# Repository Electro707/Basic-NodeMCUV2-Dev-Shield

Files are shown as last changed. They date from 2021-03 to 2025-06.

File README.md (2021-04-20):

# E707 Basic NodeMCU-V2 Shield 

PCB 3D Preview

This shield/daughterboard is for the NodeMCU V2 (also known as NodeMCU DevKit V1.0, kind of confusing) to allow a begineer to have some components to play around with. In this case, that includes a 7-segment display, an RGB LED (which is hooked up with the 7-segment display), and 3 pushbuttons.

### Arduino Library

The Arduino library for this shield can be found at: [https://github.com/Electro707/Basic-NodeMCUV2-Dev-Shield-Library](https://github.com/Electro707/Basic-NodeMCUV2-Dev-Shield-Library). It provides pin definitions and more importantly some examples to get started with.

The reason it's in a different repo is to allow for an easy download of the library as a ZIP file (using GitHub's "Download ZIP" option) to be easily imported into the Arduino IDE. 

### PCB

The PCB files can be found in the `KiCAD Files` folder. 

There are different folders for different PCB layouts. More details can be found in [KiCAD_Files/README.md](KiCAD_Files/README.md)

#### PCB Panel

There is a panel (not tested tough) of the PCB for mass-production:

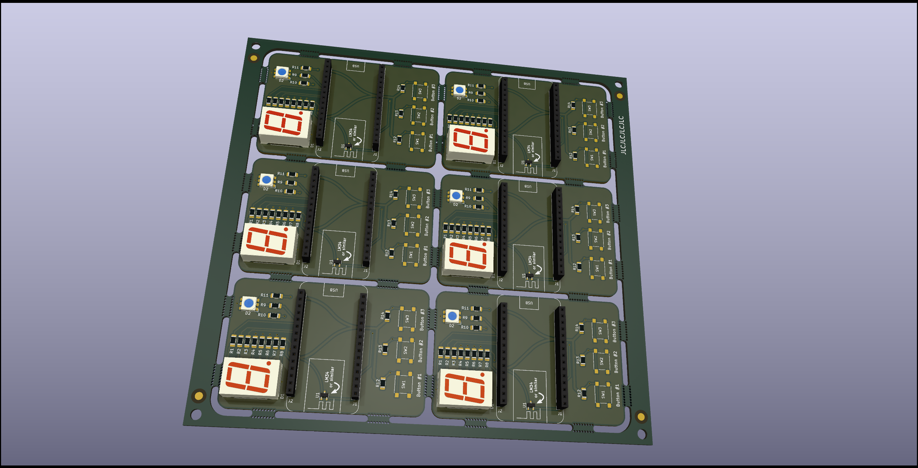
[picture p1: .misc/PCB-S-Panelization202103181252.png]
Panel Picture


##### NOTE: If you have KiCAD 5.1.9 or lower, the KiCAD files will not open as it was designed with KiCAD 5.99 (the alpha/beta version of KiCAD V6).

### Docs 
Coming Soon!

### Credits:
- Creator and Maintainer:
    - Electro707 (Jamal Bouajjaj)
- KiCAD NODEMCU V2 Symbol:
    - jdunmire -> [https://github.com/jdunmire/kicad-ESP8266](https://github.com/jdunmire/kicad-ESP8266)
- Some Icons:
    - Arduino's IDE Repo -> [https://github.com/arduino/Arduino/blob/master/build/shared/lib/theme/buttons.svg](https://github.com/arduino/Arduino/blob/master/build/shared/lib/theme/buttons.svg)

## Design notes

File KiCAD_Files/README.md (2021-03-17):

# KiCAD Files Versions

There are different folders in this directory, and they are different versions of this shield. The schematic is all the same, the difference lying in the PCB layout/footprints.

- Standard-S: The regular SMD version of the board, optimized for mass production.
- Standard-T: The regular THT version of the board, optimized to be used as a soldering kit.
- UNewHaven-S: The University of New Haven version, used for the school's "Welcome Kit" something. Optimized for mass production.

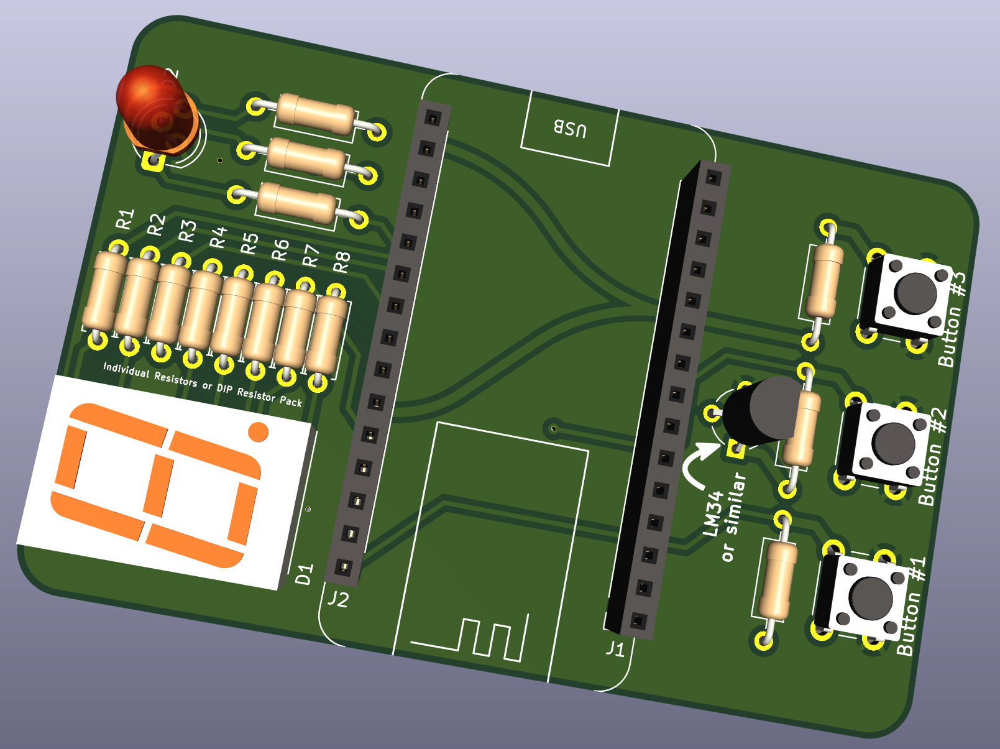
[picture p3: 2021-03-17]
.misc/Screenshot_20210317_004601.png

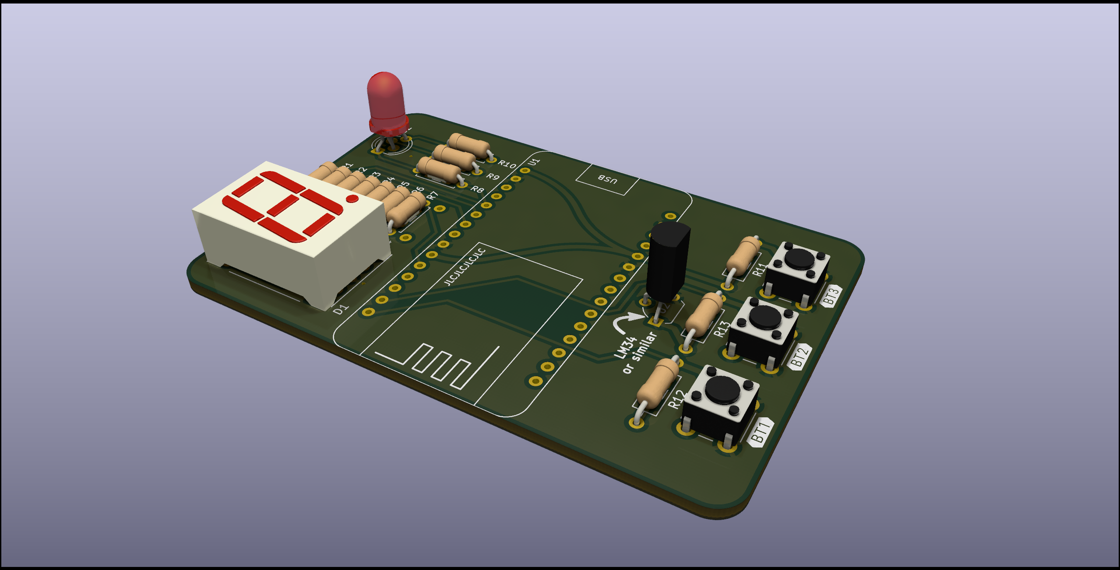
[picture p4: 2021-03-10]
.misc/pcb-prev-1.png

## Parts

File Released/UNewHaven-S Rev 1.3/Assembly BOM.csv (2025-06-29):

Comment | Designator | Footprint | LCSC
SM420561N | D1 | Display_7Segment:7SegmentLED_LTS6760_LTS6780 | C141367
LED_RGB | D2 | LED_SMD:LED_RGB_5050-6 | C784540
Conn_01x15_Female | J1,J2 | Connector_PinSocket_2.54mm:PinSocket_1x15_P2.54mm_Vertical | C124408
330 | R1,R2,R3,R4,R5,R6,R7,R8,R9,R10,R11 | Resistor_SMD:R_1206_3216Metric_Pad1.30x1.75mm_HandSolder | C17930
1k | R12,R13,R14,R15 | Resistor_SMD:R_1206_3216Metric_Pad1.30x1.75mm_HandSolder | C4410
SW_Push_DPDT | SW-T1,SW-T2,SW-T3 | Button_Switch_THT:SW_CuK_JS202011CQN_DPDT_Straight | C221666
SW_Push | SW1,SW2,SW3 | Button_Switch_SMD:SW_Push_1P1T_NO_6x6mm_H9.5mm | C136669
MCP9700AT-ETT | U1 | Package_TO_SOT_SMD:SOT-23 | C127949

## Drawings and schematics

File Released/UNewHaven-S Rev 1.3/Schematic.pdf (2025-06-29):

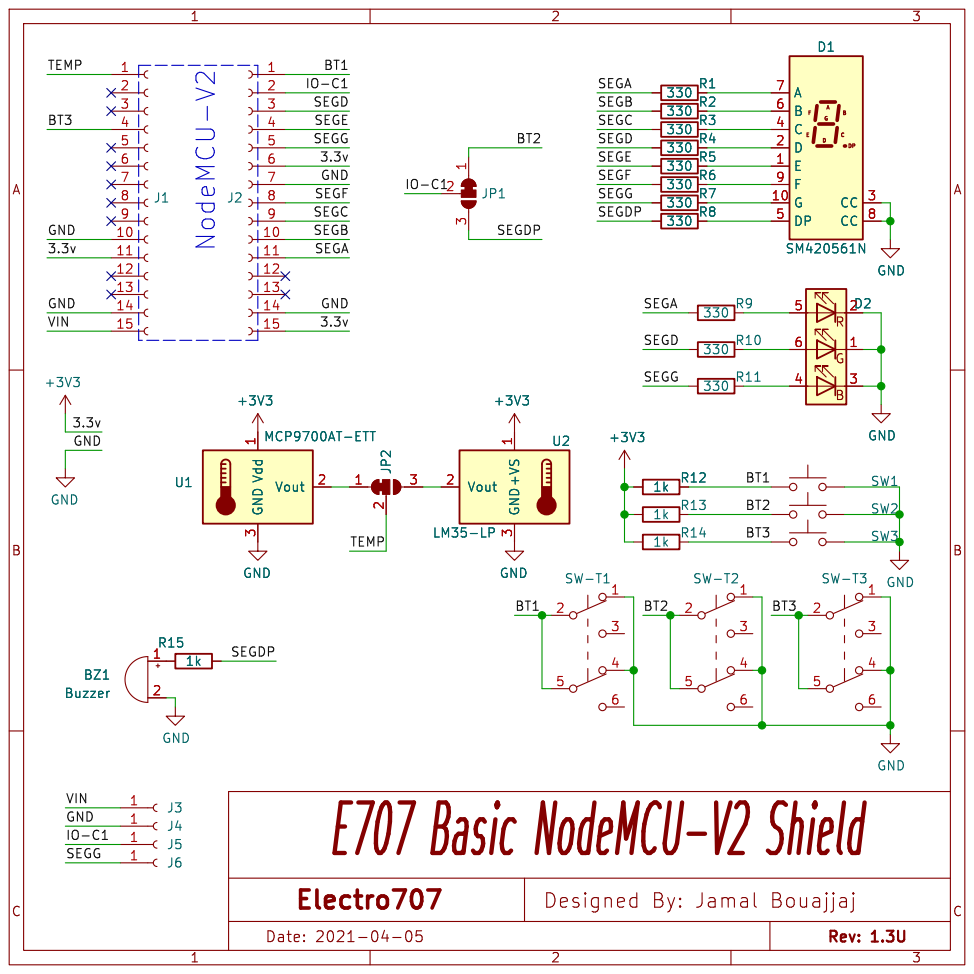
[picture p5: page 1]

E707 Basic NodeMCU-V2 Shield

Electro707

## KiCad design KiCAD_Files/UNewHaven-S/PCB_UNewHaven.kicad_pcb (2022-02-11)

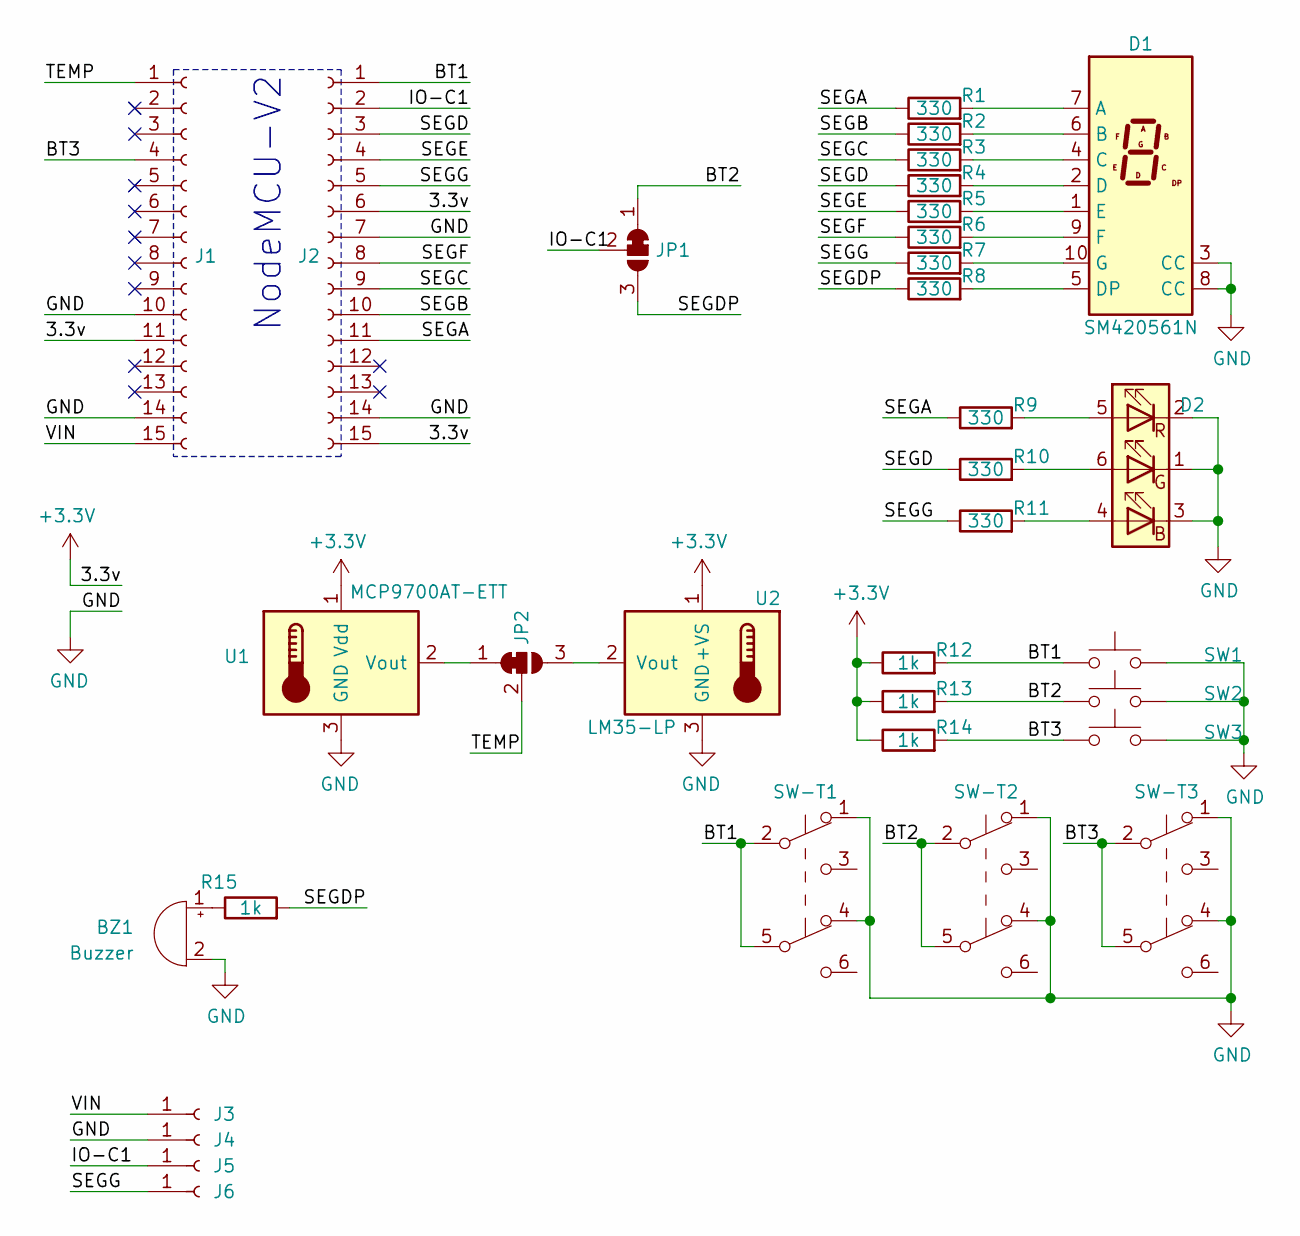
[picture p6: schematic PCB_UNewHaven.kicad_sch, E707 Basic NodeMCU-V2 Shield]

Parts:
BZ1: Buzzer; Buzzer_12x9.5RM7.6
D1: SM420561N; 7SegmentLED_LTS6760_LTS6780
D2: LED_RGB; LED_RGB_5050-6; LCSC C784540
J1, J2: Conn_01x15_Female; PinSocket_1x15_P2.54mm_Vertical
J3, J4, J5, J6: Conn_01x01_Female; SingleExternalWire
JP1, JP2: SolderJumper_3_Bridged12; SolderJumper-3_P1.3mm_Bridged12_Pad1.0x1.5mm
R1, R2, R3, R4, R5, R6, R7, R8, R9, R10, R11: 330; R_1206_3216Metric_Pad1.30x1.75mm_HandSolder
R12, R13, R14, R15: 1k; R_1206_3216Metric_Pad1.30x1.75mm_HandSolder
SW1, SW2, SW3: SW_Push; SW_Push_1P1T_NO_6x6mm_H9.5mm
SW-T1, SW-T2, SW-T3: SW_Push_DPDT; SW_CuK_JS202011CQN_DPDT_Straight
U1: MCP9700AT-ETT; SOT-23
U2: LM35-LP; TO-92L_Wide

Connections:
+3V3: J1.11, J2.6, J2.15, R12.1, R13.1, R14.1, U1.1 (Vdd), U2.1 (+VS)
/BT1: J2.1, R12.2, SW1.1, SW-T1.2 (B), SW-T1.5 (B)
/BT2: JP1.1 (A), R13.2, SW2.1, SW-T2.2 (B), SW-T2.5 (B)
/BT3: J1.4, R14.2, SW3.1, SW-T3.2 (B), SW-T3.5 (B)
/IO-C1: J2.2, J5.1, JP1.2 (C)
/SEGA: J2.11, R1.1, R9.1
/SEGB: J2.10, R2.1
/SEGC: J2.9, R3.1
/SEGD: J2.3, R4.1, R10.1
/SEGDP: JP1.3 (B), R8.1, R15.2
/SEGE: J2.4, R5.1
/SEGF: J2.8, R6.1
/SEGG: J2.5, J6.1, R7.1, R11.1
/TEMP: J1.1, JP2.2 (C)
/VIN: J1.15, J3.1
GND: BZ1.2 (+), D1.3 (CC), D1.8 (CC), D2.1 (GK), D2.2 (RK), D2.3 (BK), J1.10, J1.14, J2.7, J2.14, J4.1, SW1.2, SW2.2, SW3.2, SW-T1.1 (A), SW-T1.4 (A), SW-T2.1 (A), SW-T2.4 (A), SW-T3.1 (A), SW-T3.4 (A), U1.3 (GND), U2.3 (GND)
unnamed: BZ1.1 (-), R15.1
unnamed: D1.1 (E), R5.2
unnamed: D1.2 (D), R4.2
unnamed: D1.4 (C), R3.2
unnamed: D1.5 (DP), R8.2
unnamed: D1.6 (B), R2.2
unnamed: D1.7 (A), R1.2
unnamed: D1.9 (F), R6.2
unnamed: D1.10 (G), R7.2
unnamed: D2.4 (BA), R11.2
unnamed: D2.5 (RA), R9.2
unnamed: D2.6 (GA), R10.2
unnamed: JP2.1 (A), U1.2 (Vout)
unnamed: JP2.3 (B), U2.2 (Vout)

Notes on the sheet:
NodeMCU-V2

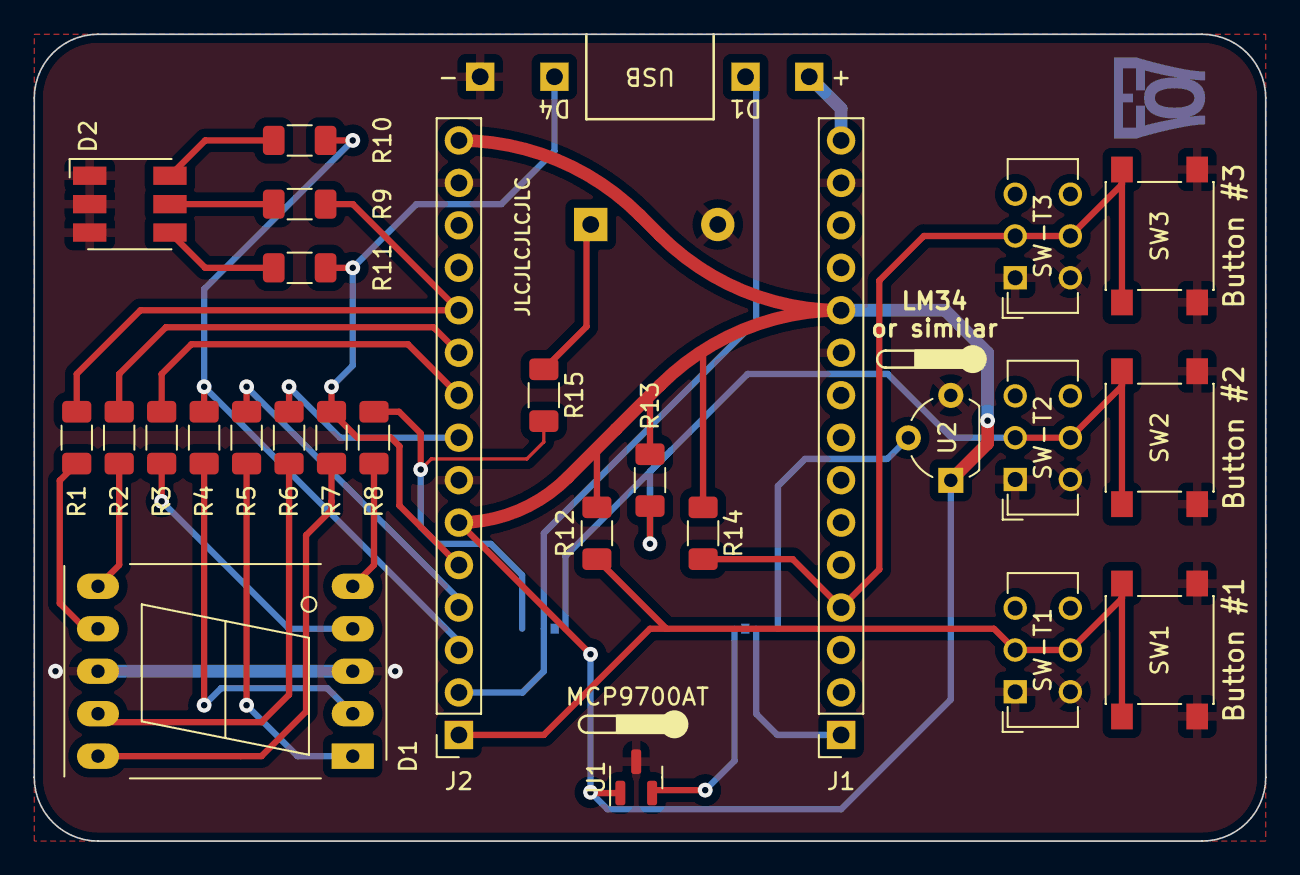
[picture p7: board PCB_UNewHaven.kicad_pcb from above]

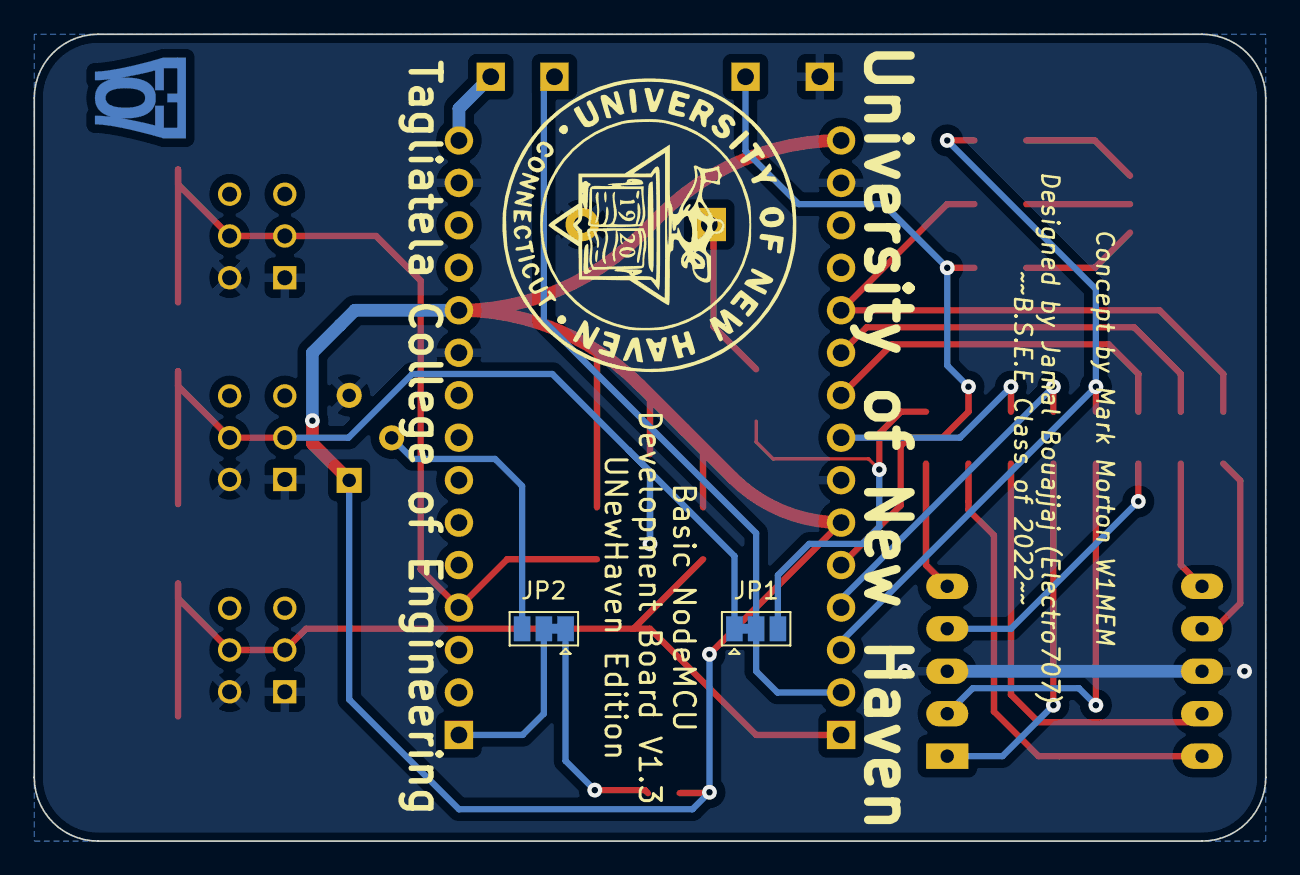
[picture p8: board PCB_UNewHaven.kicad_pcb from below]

Board: 2 copper layers, 73.7 x 48.3 mm, 36 parts (4 on the bottom side), 30 nets.

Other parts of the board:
Ref**: Val**; NPN_6x6mm
Ref**#2: Val**; NPN_6x6mm

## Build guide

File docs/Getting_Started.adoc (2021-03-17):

= E707 Basic NodeMCU-V2 Shield V1.1 Getting Started Guide
Electro707
V1.1, 2021-03-17
:toc:
:icons: font
// :doctype: book
:imagesdir: .images
<<<
== Intro
The purpose of this document is to be used as a "Getting Started" guide for the E707 Basic NodeMCU-V2 Shield. This document has been written for a beginner (somebody who has little to no experience with Arduino's or electronics) to get them up and running with the shield and upload a basic example to it.

NOTE: About the name of this board, the reason I have added `V2` to the `NodeMCU-V2` part of the name is to distuguishe that this shield is only compatible with that is widely refered as NodeMCU V2, instead of other varients/versions of the NodeMCU. The shield's version is what comes after the `Shield` part of the name. Sorry for any confusion.

== Prerequesites
=== Components
You should have the following 2 parts:

[cols="1,1"]
|===
|A NodeMCU V2 Development Board
|E707 Basic NodeMCU-V2 Shield

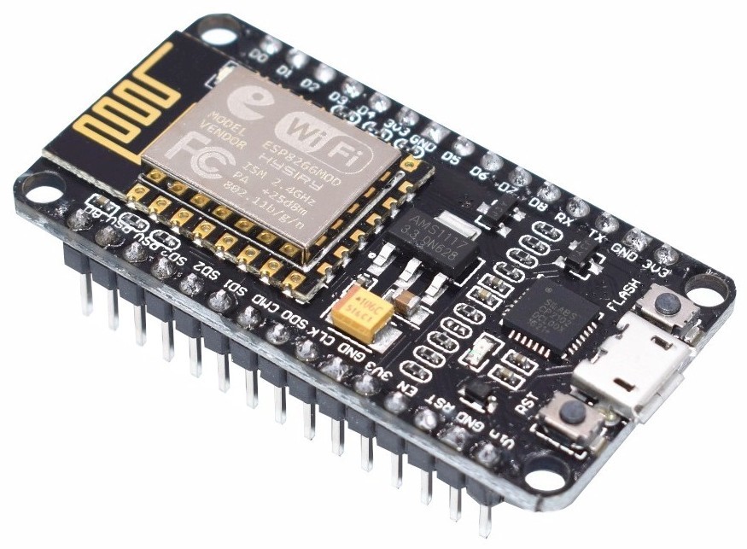
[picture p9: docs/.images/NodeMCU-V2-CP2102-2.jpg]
NodeMCU V2 Board Image
a|
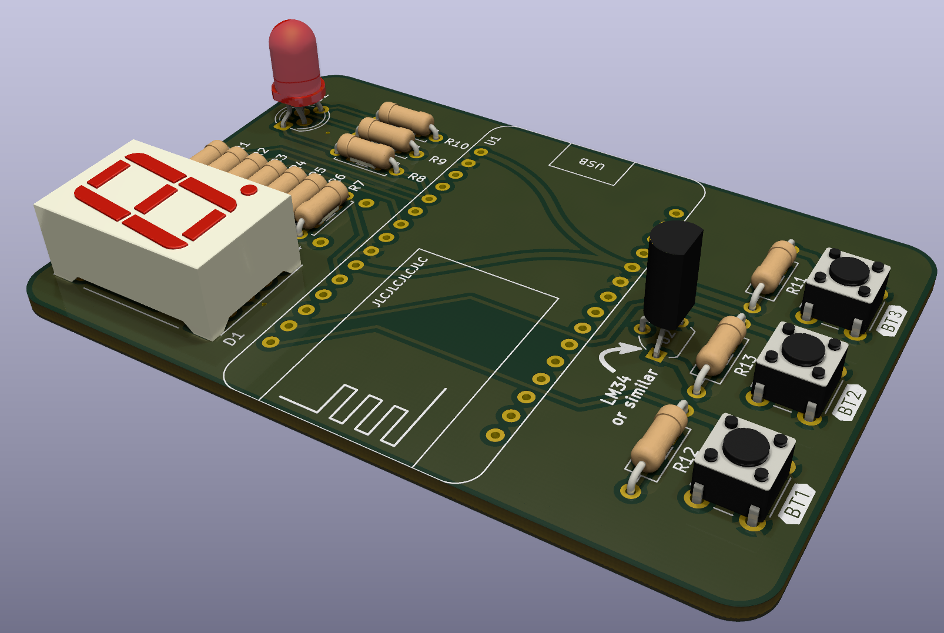
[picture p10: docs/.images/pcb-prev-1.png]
E707 Shield
a|
|===

If the NodeMCU isn't already plugged into the shield (plug it into the 2 pin headers on the board). 

NOTE: This assumes that the shield is already soldered. If it isn't and you have a plain PCB and components, checkout the Soldering Guide.

=== Software
==== Arduino IDE
We will be using the Arduino IDE (Integrated Development Environment) to create programs and upload them to the NodeMCU. While it is the most common way of doing so, there are other tools and IDEs out there like MicroPython for examples. 

If you don't have the Arduino IDE installed on you machine, you should do that now. The program's download page can be found at https://www.arduino.cc/en/software. They have a https://www.arduino.cc/en/Guide[Getting Started Guide] if you're having trouble installing the program.

==== ESP8266 Board Package
When you first install the Arduino IDE, it doesn't come with the ability to upload to ESP8266 based modules (like the NodeMCU), so we must add that. Open up the IDE and go into ``File->Preferences``. In the __Additional Board Managers URLs__ section, enter the following URL:
 
 https://arduino.esp8266.com/stable/package_esp8266com_index.json

This allows us to use the build-in Board Manager to install ESP8266 board. After that, exit out of the preferences menu (by clicking the __OK__ button) and go into ``Tools->Board->Board Manager``. Once the Board Manager menu pops us, type in `esp8266` in the filter entry and press Enter. You should see an `esp8266 by ESP8266 Community` board popup. 

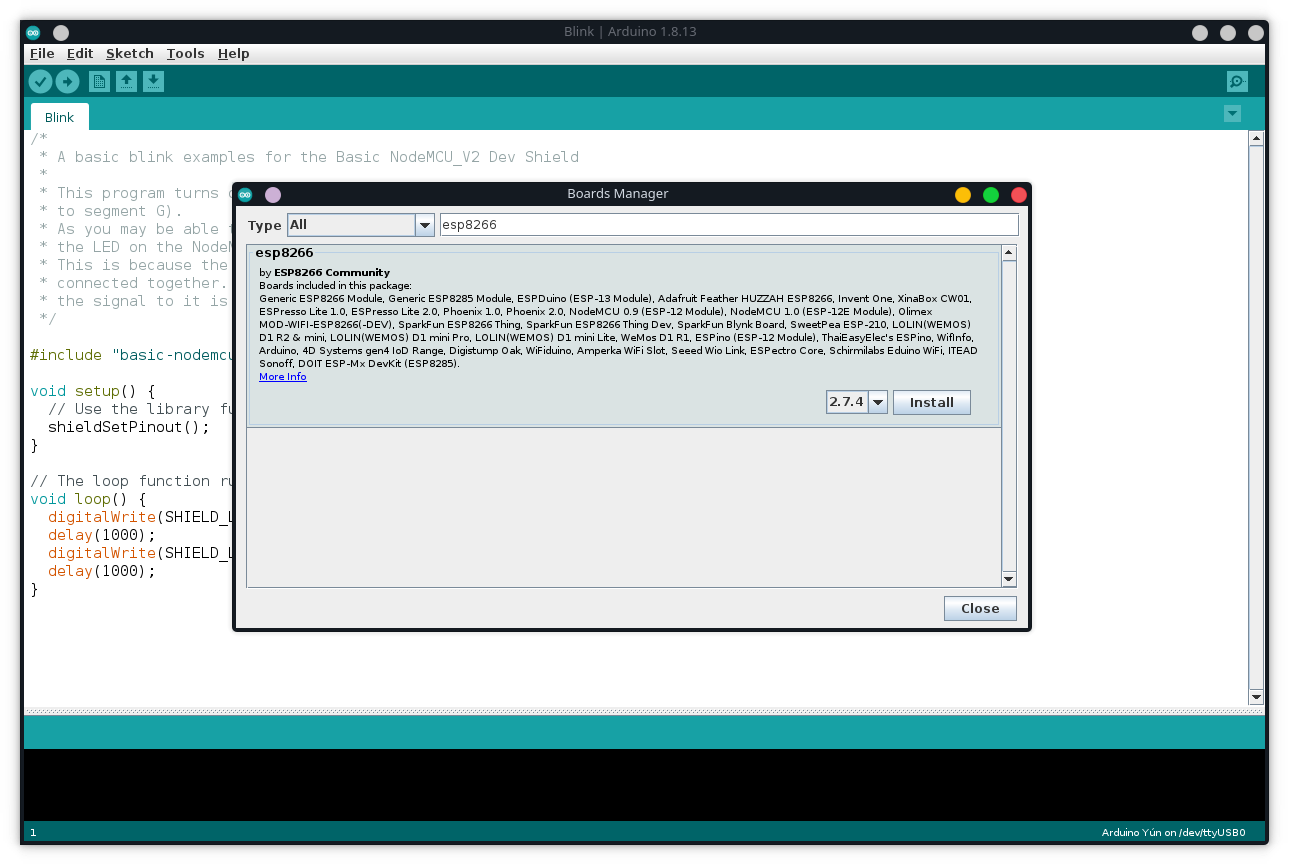
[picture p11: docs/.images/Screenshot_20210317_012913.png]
Board Manager image with esp8266


Click on the Install button for that board. The download and installation process might take a hot minute, so grab a quick cup of coffee in the meanwhile (or tea which is my personal favorite). After the installation process is complete, close out of the Board Manager (with the Close button). You are now able to compile and upload programs to ESP8266 based modules including the NodeMCU which we are using.

== E707 Basic NodeMCU-V2 Shield Library
While you can go right ahead and start using the shield by reading the schematic and seeing which periferals connect to where, a library was made for this shield to make that process simpler. It includes pin definitions, some helper functions (for the temperature sensor for example), and examples. 

To download the library, head over to it's repository on GitHub:

 https://github.com/Electro707/Basic-NodeMCUV2-Dev-Shield-Library

Then click on the ``Code->Download Zip`` button on the Github page to get a .zip file of the library. In the Arduino IDE, go to ``Sketch->Include Library->Add .ZIP Library``. Browse to the download location of the library and select it. 

== Lets Light This Place Up
Now let's make some LEDs blink on the Dev. Shield. Go to and select ``Files->Examples->E707 Basic NodeMCU-V2 Shield->Blink``. A new sketch should pop up with some pre-written code. 

New let's select the right board to compile and upload to. In the Tools menu, for the Board select `NodeMCU 1.0 (ESP-12E Module)` board. The rest of the settings should be fines, and it should look like the following:

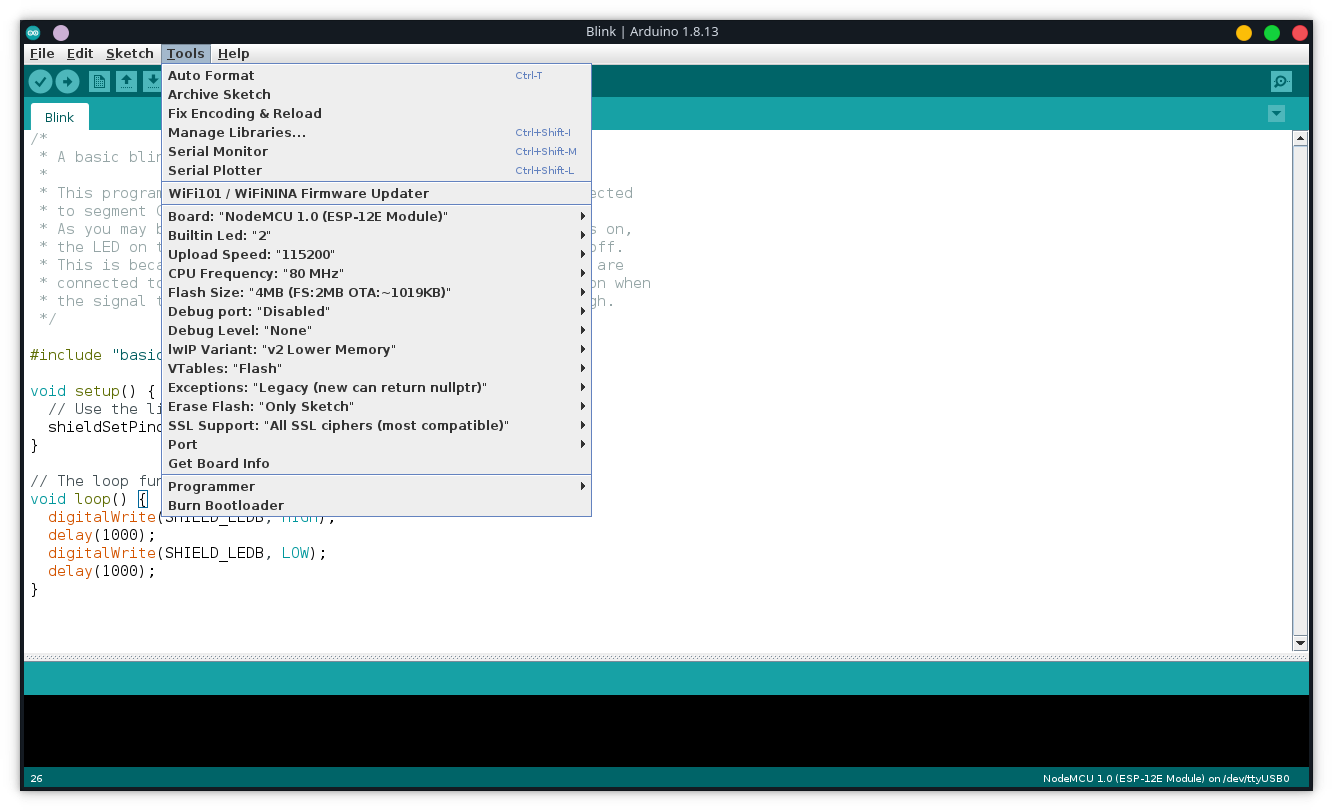
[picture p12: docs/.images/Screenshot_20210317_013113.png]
IDE Image with Tools open


NOTE: The reason why the esp8266 board manager calls the `NodeMCU-V2 -> NodeMCU 1.0 (ESP-12E Module)` is because the terminology `NodeMCU V2` is the widely used terminology by the community, while the board version is technically v1.0 from NodeMCU, and what is refered to as `NodeMCU V1` is technically board version v0.9. Yeah it's kind of confusing

Now let's compile the Blink example we just loaded (turning the human-readable code into machine code). Click on the  Compile button in the IDE. If all goes well, the IDE's status bar should say `Done Compiling`. 
Now let's plug in the NodeMCU Board into the computer. Use a MicroUSB cable to connect the NodeMCU module to the computer.
Now go into the Tools menu, and in the Port submenu chose a COM port that isn't COM1 which should appear (or for Linux and Mac users the port which isn't `dev/ttyS0`). 
Now we are able to upload the program, and we do that by clicking on the  Upload button in the IDE. When the status bar of the IDE says `Done Uploading`, the program has been uploaded to the board. 

You should start noticing that the shield's blue LED (and the middle segment on the 7 segment display) should start blinking. If that's the case, CONGRATULATIONS, you just uploaded a program on the NodeMCU board with the E707 Basic NodeMCU-V2 Shield. 

== Now What?
Well really that's up to you. There is a vast possibility of what you can do with the NodeMCU board and the shield, and we've only done a tiny fraction of what's it's capable of (and we haven't started using the Wifi part of the NodeMCU). There are plenty of examples that you can try out, which the ESP8266 board package and the E707 Basic NodeMCU-V2 Shield's library provides. 

Now go out there and have fun!

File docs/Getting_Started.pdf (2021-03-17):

# E707 Basic NodeMCU-V2 Shield V1.1 Getting Started Guide

# Table of Contents

# Intro

The purpose of this document is to be used as a "Getting Started" guide for the E707 Basic NodeMCU-V2 Shield. This document has been written for a beginner (somebody who has little to no experience with Arduino’s or electronics) to get them up and running with the shield and upload a basic example to it.

About the name of this board, the reason I have added V2 to the NodeMCU-V2 part of the name is to distuguishe that this shield is only compatible with that is widely refered as NodeMCU V2, instead of other varients/versions of the NodeMCU. The shield’s version is what comes after the Shield part of the name. Sorry for any confusion.

# Prerequesites

# Components

You should have the following 2 parts:

A NodeMCU V2 Development Board | E707 Basic NodeMCU-V2 Shield

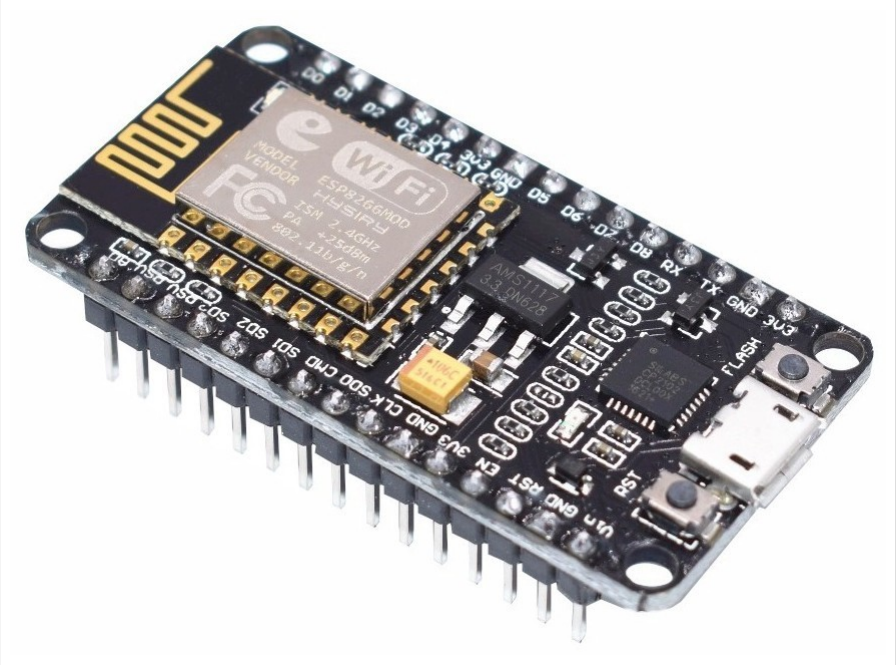
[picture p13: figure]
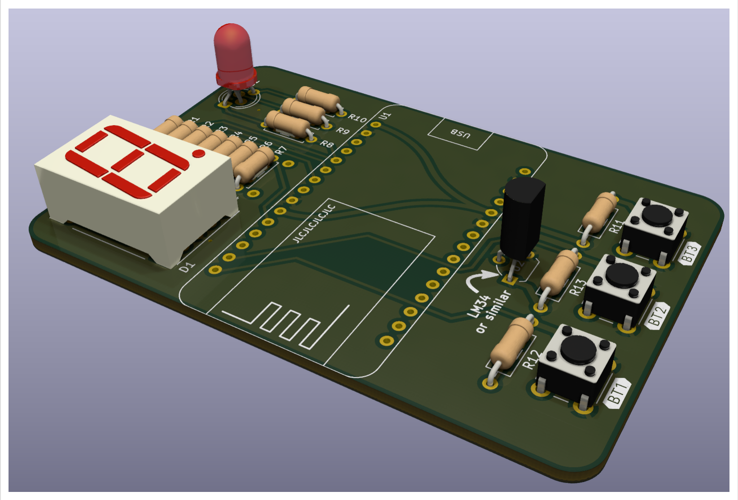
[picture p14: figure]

If the NodeMCU isn’t already plugged into the shield (plug it into the 2 pin headers on the board).

This assumes that the shield is already soldered. If it isn’t and you have a plain PCB and components, checkout the Soldering Guide.

# Software

### Arduino IDE

We will be using the Arduino IDE (Integrated Development Environment) to create programs and upload them to the NodeMCU. While it is the most common way of doing so, there are other tools and IDEs out there like MicroPython for examples.

If you don’t have the Arduino IDE installed on you machine, you should do that now. The program’s download page can be found at https://www.arduino.cc/en/software. They have a Getting Started Guide (https://www.arduino.cc/en/Guide) if you’re having trouble installing the program.

### ESP8266 Board Package

When you first install the Arduino IDE, it doesn’t come with the ability to upload to ESP8266 based modules (like the NodeMCU), so we must add that. Open up the IDE and go into File→Preferences. In the Additional Board Managers URLs section, enter the following URL:

https://arduino.esp8266.com/stable/package_esp8266com_index.json

This allows us to use the build-in Board Manager to install ESP8266 board. After that, exit out of the preferences menu (by clicking the OK button) and go into Tools→Board→Board Manager. Once the Board Manager menu pops us, type in esp8266 in the filter entry and press Enter. You should see an
esp8266 by ESP8266 Community board popup.

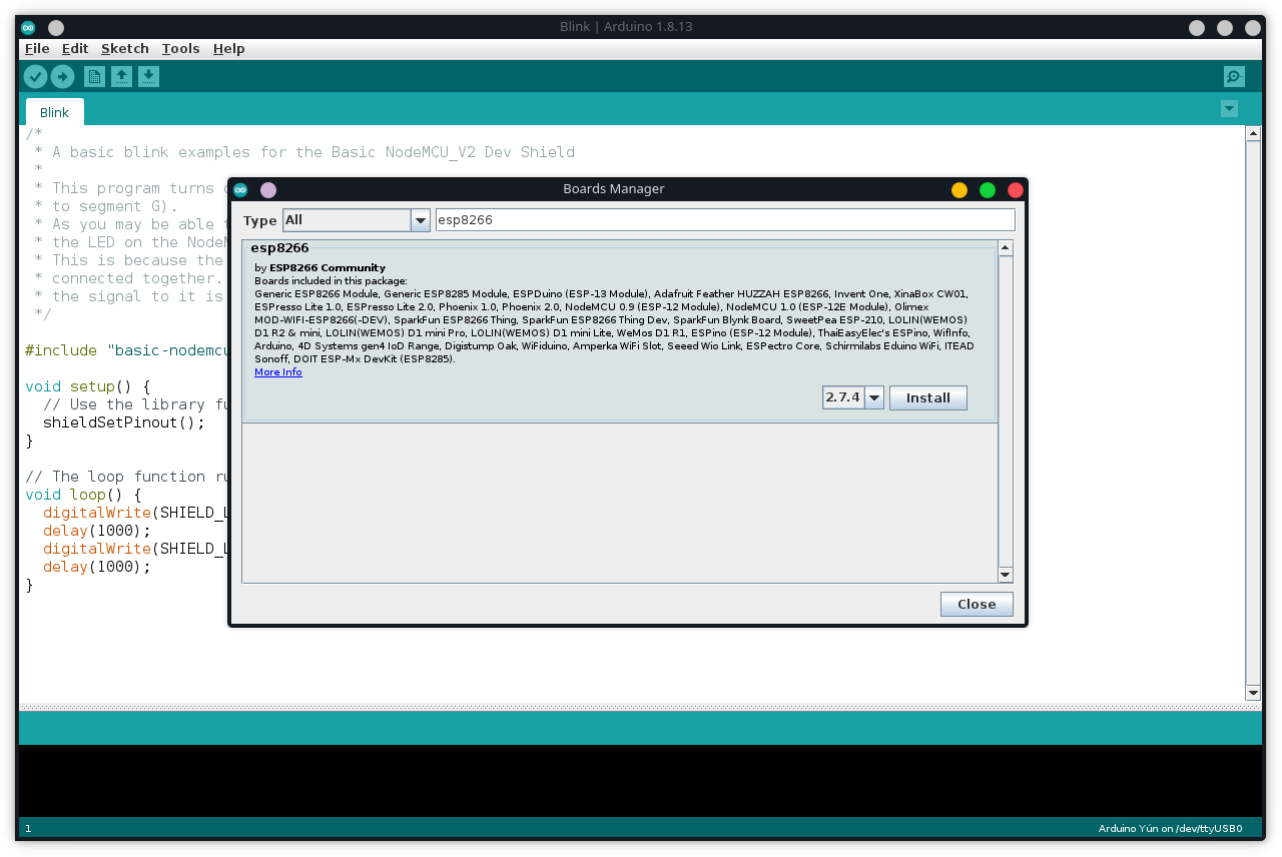
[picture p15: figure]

Click on the Install button for that board. The download and installation process might take a hot minute, so grab a quick cup of coffee in the meanwhile (or tea which is my personal favorite). After the installation process is complete, close out of the Board Manager (with the Close button). You are now able to compile and upload programs to ESP8266 based modules including the NodeMCU which we are using.

# E707 Basic NodeMCU-V2 Shield Library

While you can go right ahead and start using the shield by reading the schematic and seeing which periferals connect to where, a library was made for this shield to make that process simpler. It includes pin definitions, some helper functions (for the temperature sensor for example), and examples.

To download the library, head over to it’s repository on GitHub:

https://github.com/Electro707/Basic-NodeMCUV2-Dev-Shield-Library

Then click on the Code→Download Zip button on the Github page to get a .zip file of the library. In the Arduino IDE, go to Sketch→Include Library→Add .ZIP Library. Browse to the download location of the library and select it.

# Lets Light This Place Up

Now let’s make some LEDs blink on the Dev. Shield. Go to and select Files→Examples→E707 Basic NodeMCU-V2 Shield→Blink. A new sketch should pop up with some pre-written code.

New let’s select the right board to compile and upload to. In the Tools menu, for the Board select NodeMCU 1.0 (ESP-12E Module) board. The rest of the settings should be fines, and it should look like the following:

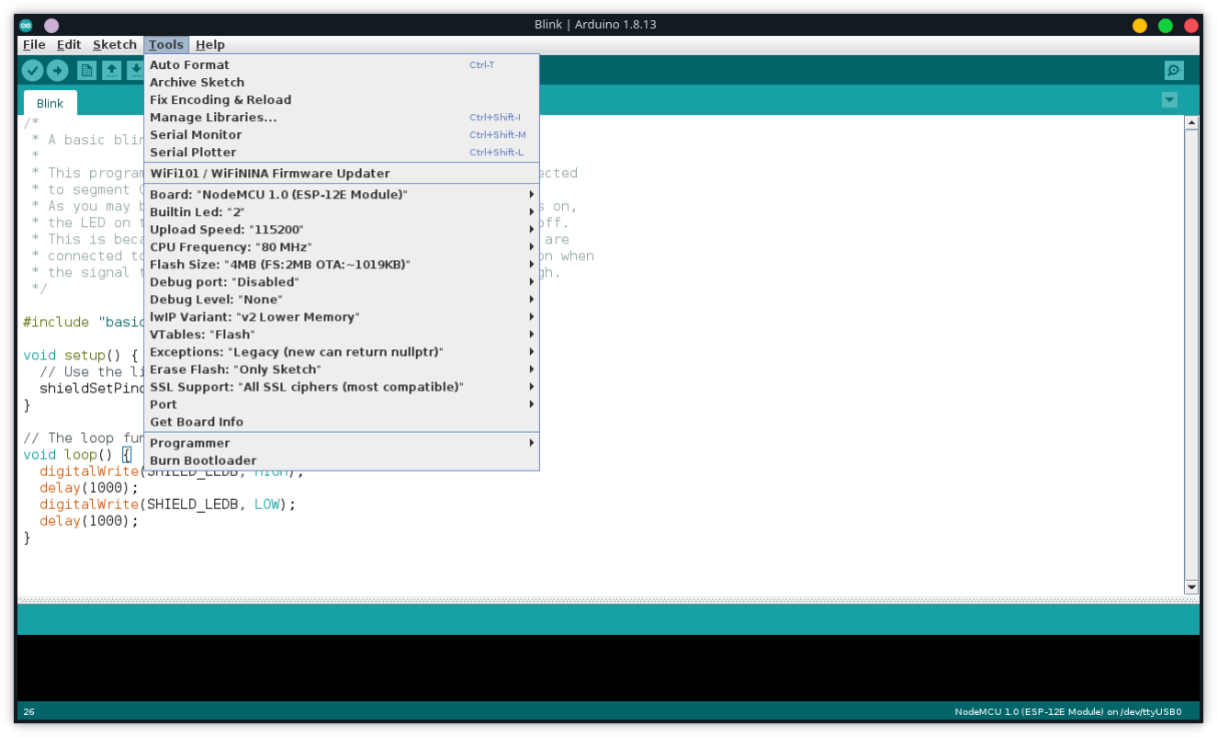
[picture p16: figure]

The reason why the esp8266 board manager calls the NodeMCU-V2 → NodeMCU 1.0 (ESP-12E Module) is because the terminology NodeMCU V2 is the widely used terminology by the community, while the board version is technically v1.0 from NodeMCU, and what is refered to as NodeMCU V1 is technically board version v0.9. Yeah it’s kind of confusing

Now let’s compile the Blink example we just loaded (turning the human-readable code into machine code). Click on the Compile button in the IDE. If all goes well, the IDE’s status bar should say Done Compiling. Now let’s plug in the NodeMCU Board into the computer. Use a MicroUSB cable to connect the NodeMCU module to the computer. Now go into the Tools menu, and in the Port submenu chose a COM port that isn’t COM1 which should appear (or for Linux and Mac users the port which isn’t dev/ttyS0). Now we are able to upload the program, and we do that by clicking on the Upload button in the IDE. When the status bar of the IDE says Done Uploading, the program has been uploaded to the board.

You should start noticing that the shield’s blue LED (and the middle segment on the 7 segment display) should start blinking. If that’s the case, CONGRATULATIONS, you just uploaded a program on the NodeMCU board with the E707 Basic NodeMCU-V2 Shield.

# Now What?

Well really that’s up to you. There is a vast possibility of what you can do with the NodeMCU board and the shield, and we’ve only done a tiny fraction of what’s it’s capable of (and we haven’t started using the Wifi part of the NodeMCU). There are plenty of examples that you can try out, which the ESP8266 board package and the E707 Basic NodeMCU-V2 Shield’s library provides.

Now go out there and have fun!

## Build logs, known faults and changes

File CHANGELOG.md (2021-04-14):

# CHANGELOG

Here are the changelogs and maybe some TODOs for self-tracking of what to do:

- V1:
  - Initial Release. Nothing to see here
- V1.1:
  - Added SMD, THT, and a UNewHaven versions of the board (the last one is mainly due to how the project got started and to seperate the UNewHaven markings from the main project). The THT version will be for a soldering kit of sorts, and the SMD version will be mass production.
  - Changed the button's label to just text, as Buzzard's output is to small for a prototype fabhouse to show well.
  - Changed the NodeMCU symbol to 2 headers, so that they are exportable as 2 components in BOMs and footprint placement for assembly.

The changes from here on-hout are going to be seperated per board version
- UNewHaven Board
  - V1.2:
    - Changed the RGB LED to an SMD footprint
    - Added SMD analog temperature sensor
    - Minor changes in silkscreen (not indicates the temperature sensor). 
    - Added JLCPCB drill marks for assembly

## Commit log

2021-03-10 Updated Schematic. Started a Getting Started guide
    [V1.kicad_pcb, V1.kicad_sch]
2021-03-10 Changed name in docs. Added some Arduino icons
2021-03-15 Added .net file. Changed origin. Last commit for V1 PCB
    [V1.kicad_pcb, V1.kicad_sch, V1_UNewHaven.kicad_pcb]
2021-03-15 Changed PCB design name to PCB instead of V1
    [PCB.kicad_pcb, PCB.kicad_sch, PCB_UNewHaven.kicad_pcb]
2021-03-15 Started working on V1.1 of the PCB. Many more changes needed
    [PCB.kicad_sch]
2021-03-15 Some residual changes from last commit
    [PCB.kicad_pcb]
2021-03-17 Pushing Version 1.1, all 3 versions of it
    [PCB-S.kicad_pcb, PCB-S.kicad_sch, PCB.kicad_pcb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]
2021-03-18 Added Panelization files and stuff
    [BOM.csv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]
2021-04-14 UNewHaven Version 1.2 Update. Removed project from pre-release in README.md
    [PCB.kicad_pcb, PCB_UNewHaven.kicad_pcb, PCB_UNewHaven.kicad_sch]
2021-10-07 Almost finished Rev1.3 of the UNewHaven board
    [PCB_UNewHaven.kicad_pcb, PCB_UNewHaven.kicad_sch]
2022-01-23 Added some external pin headers
    [PCB_UNewHaven.kicad_pcb, PCB_UNewHaven.kicad_sch]
2022-02-11 Changed the external pinout's connectors. Minor silk changes. DRC fixes
    [PCB_UNewHaven.kicad_pcb, PCB_UNewHaven.kicad_sch]
2022-02-14 Added LCSC component attributes
    [PCB_UNewHaven.kicad_sch]
2025-06-29 Added some 'released' files
    [Assembly BOM.csv, Assembly Top Placement.csv]
